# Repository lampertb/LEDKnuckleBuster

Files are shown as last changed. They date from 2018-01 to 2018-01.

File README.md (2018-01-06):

[gif]: https://github.com/lampertb/LEDKnuckleBuster/blob/master/Images/touchExample.gif "LED Knuckle Buster In Action"
[datasheet]: https://github.com/lampertb/LEDKnuckleBuster/blob/master/Images/datasheet.png "Darlington NPN Datasheet"
[dxfExample]: https://github.com/lampertb/LEDKnuckleBuster/blob/master/Images/dxfExample.png "Exporting DXF Design"
[equation1]: https://github.com/lampertb/LEDKnuckleBuster/blob/master/Images/equation1.png "Base current equation"
[equation2]: https://github.com/lampertb/LEDKnuckleBuster/blob/master/Images/equation2.png "Base current equation"
[equation3]: https://github.com/lampertb/LEDKnuckleBuster/blob/master/Images/equation3.png "Base current equation"

[handFist]: https://github.com/lampertb/LEDKnuckleBuster/blob/master/Images/handFist.jpg "LED Knuckle Buster In Action"
[layout]: https://github.com/lampertb/LEDKnuckleBuster/blob/master/Images/layout.png "Board layout with fill"
[productPhoto]: https://github.com/lampertb/LEDKnuckleBuster/blob/master/Images/productPhoto.jpg "LED Knuckle Buster In Action"
[schematic]: https://github.com/lampertb/LEDKnuckleBuster/blob/master/Images/schematic.png "LED Knuckle Buster Schematic"

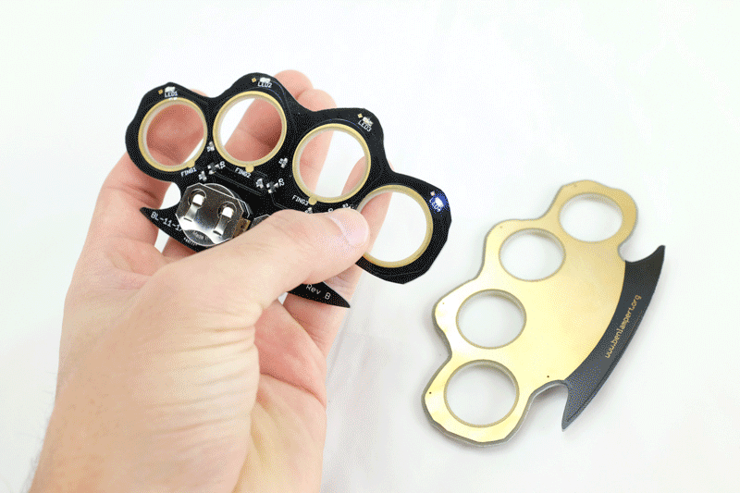
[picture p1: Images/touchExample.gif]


# LED Knuckle Busters, light up your fists!
## By Ben Lampert

Designed and manufactured by Ben Lampert at Chicago's mHub maker space (https://mhubchicago.com/) these LED's brass knuckles are a fun toy to play with. Conductive finger holes turn on high gain transistors that lights up LED's based on the strength of the grip; just put your fingers through the hole and squeeze!

* Features:
  * Brass knuckle finger spacing fits most adults and children.
  * 100% Analog circuitry features low power operation when not in use.
  * Touch sensitive design, just make a fist to turn on the LED's!

* Requires:
  * Blue LED Brass Knuckle board (.brd files available)
  * Parts http://www.digikey.com/short/q8q7pt

* Specs
  * Height: Approx 115mm
  * Width: Approx 50mm
  * Powered by two coin cell batteries

## Project Details:

The LED Knuckle Buster mechanical and board outline was originally inspired by this thingiverse brass knuckle.
https://www.thingiverse.com/thing:1160010

I decided to make an LED version, and after downloading used solidworks to create and exporting a DXF of the outer perimeter of the model. This DXF was then important as layer 20 (board outline) in eagle to create the PCB board outline.

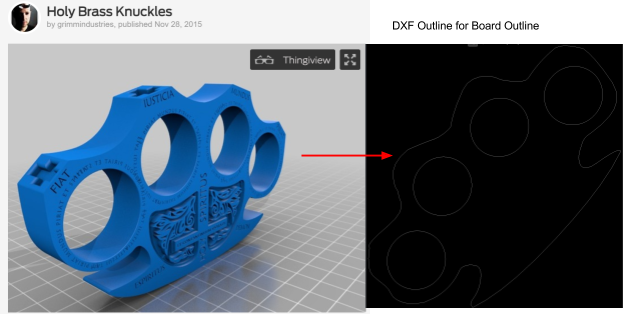
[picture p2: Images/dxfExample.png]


The circuit I think it pretty clever. I originally thought to use a microcontroller and a technique similar to the mAkey mAkey (https://makeymakey.com/). However, it seems like I put MCU’s on everything these days, so I revisited a 100% analog design.

What I came up with I think it simple and clever. The copper on the backside of the board is a VCC plan, as the fingers extend through the holes that make contact with the base of a darlignton pair. Given you skin resistivity is ~100k (https://www.ncbi.nlm.nih.gov/pmc/articles/PMC2763825/) you get a small amount of current running through your fingers.

Just as a ballpark, that current using a Darlington Pair is approximately:







Reviewing the cheapest Darlington Pair NPN available on Digikey
https://www.diodes.com/assets/Datasheets/ds30047.pdf

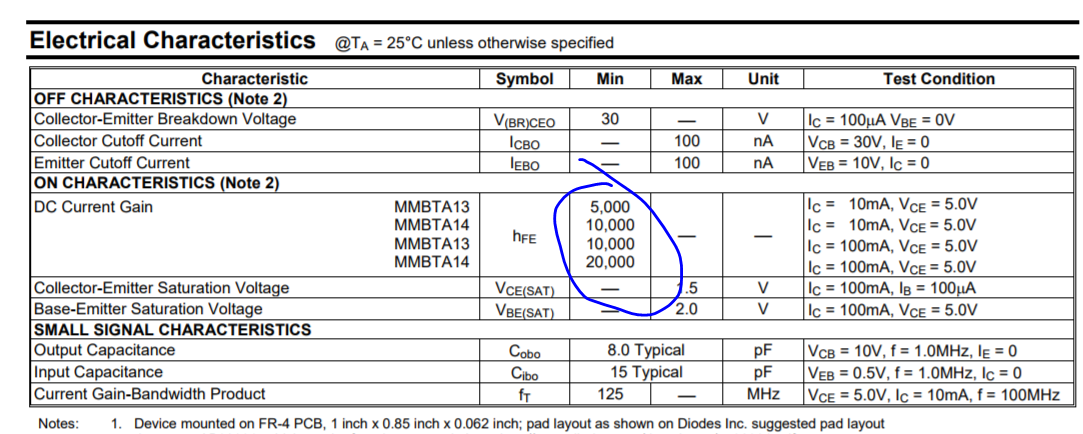
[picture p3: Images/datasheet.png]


This has a gain of 5,000-10,000. So our 46uA base current becomes 23-46mA of current. Not bad for small leakage through your finger!

That current is plenty to turn on a LED, so with that in mind this is the final circuit I designed.

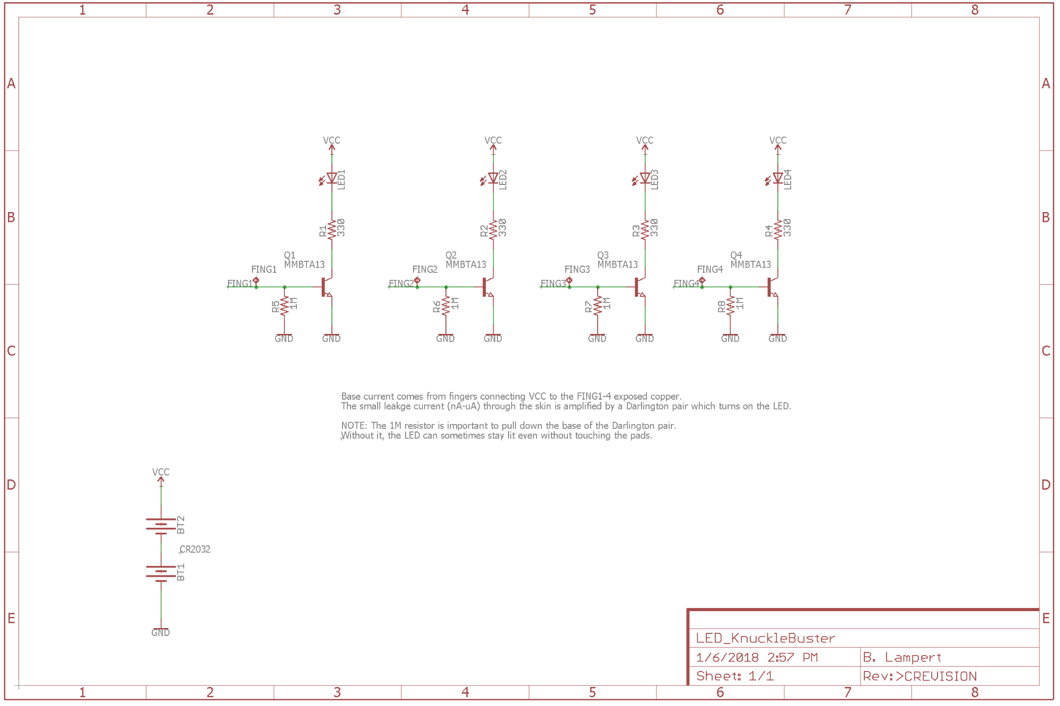
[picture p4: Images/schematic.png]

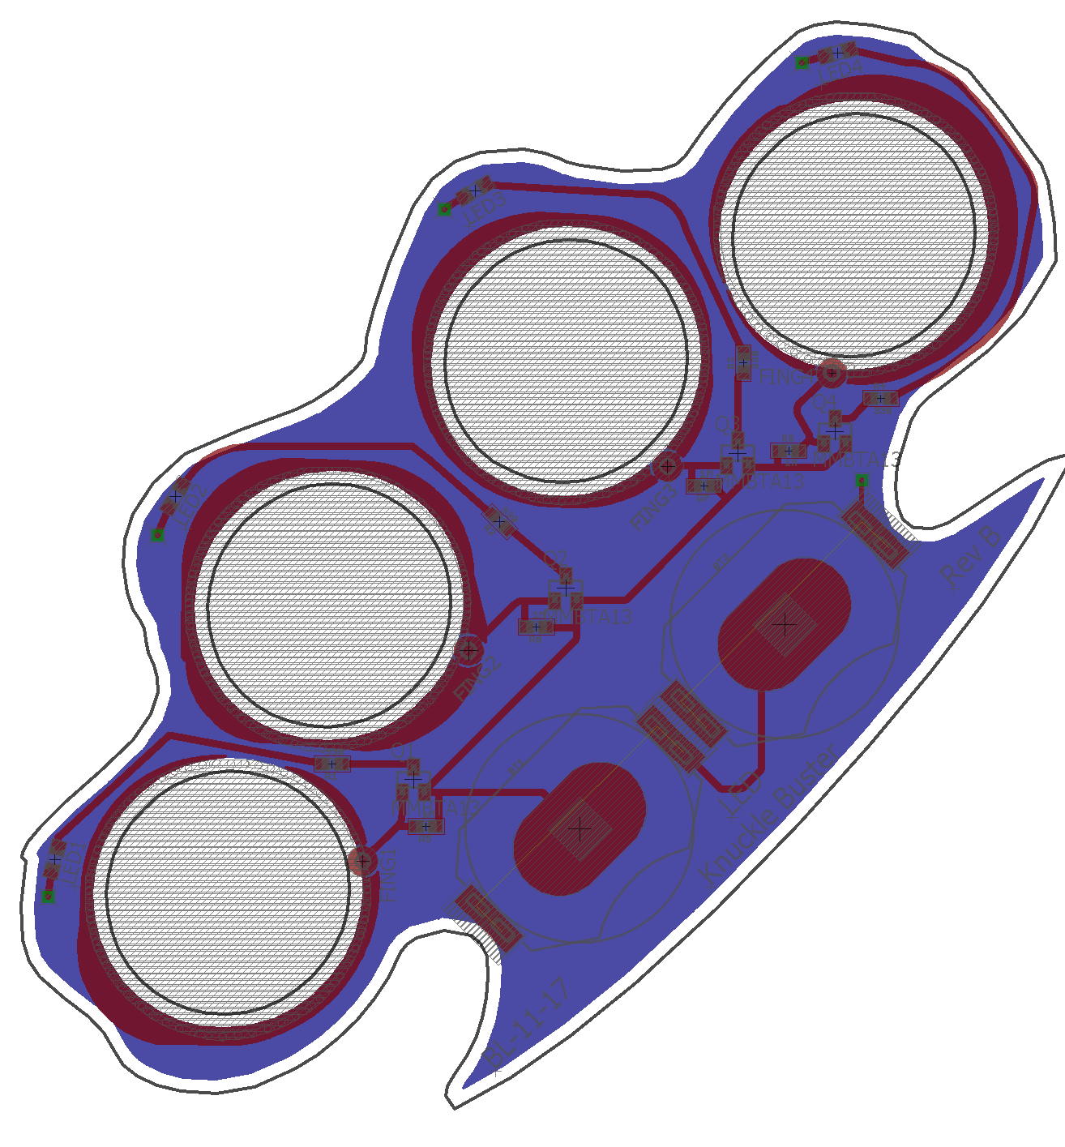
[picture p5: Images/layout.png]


Rev A:
Forgot to connect the via for VCC to connect to the other side of the board, whoop!
Also, forgot a pull down on the base which caused FING4 LED to always be on.

Rev B:
Everything is tested ok! Time to Ship It!

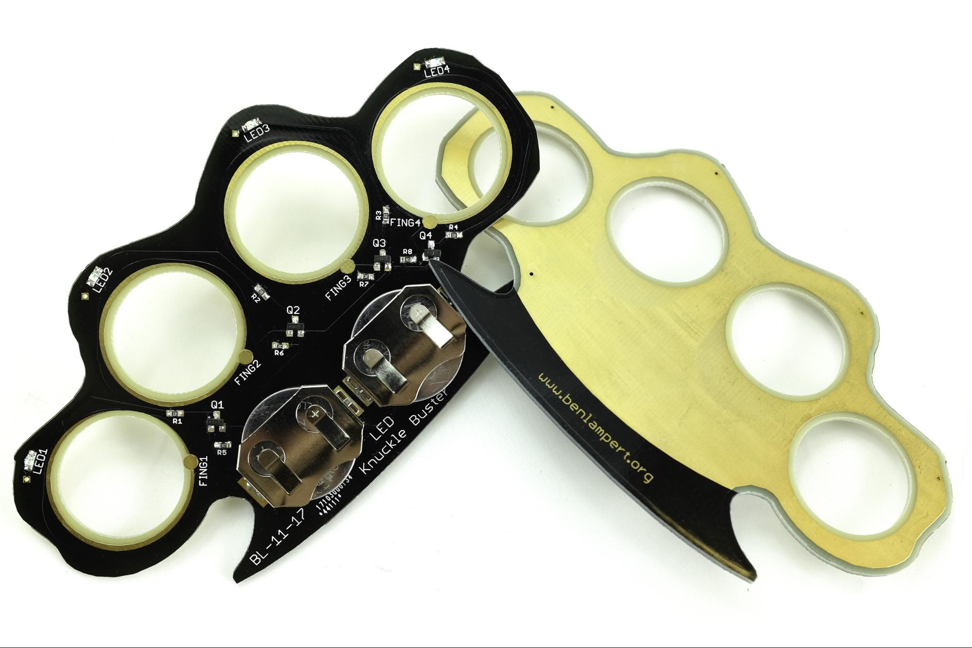
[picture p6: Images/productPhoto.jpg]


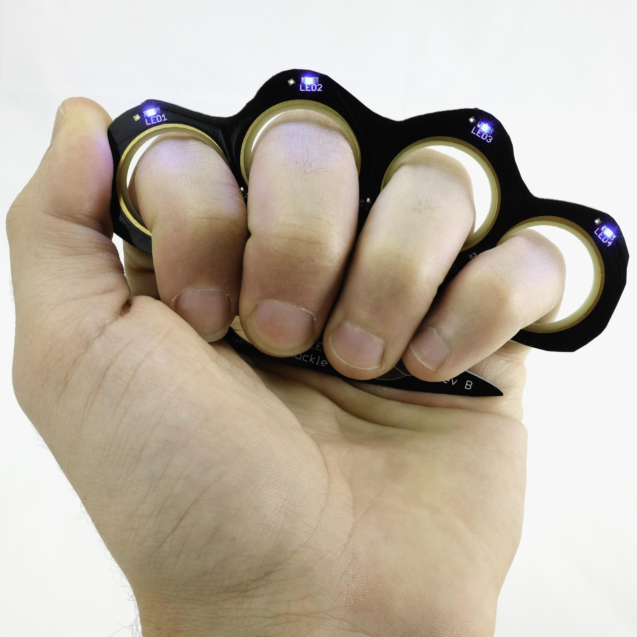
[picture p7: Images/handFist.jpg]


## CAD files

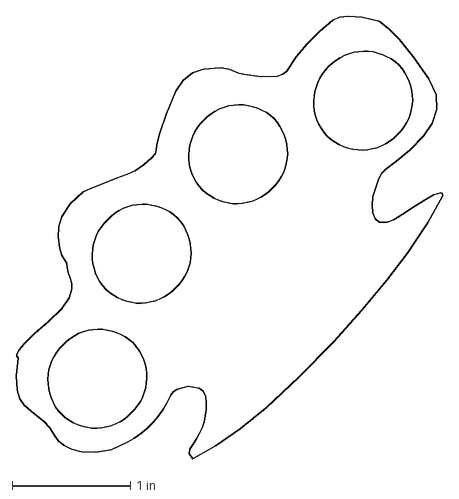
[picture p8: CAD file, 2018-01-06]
Mechanical/Knuckle_Buster_Outline.DXF
3.61 x 3.75 in

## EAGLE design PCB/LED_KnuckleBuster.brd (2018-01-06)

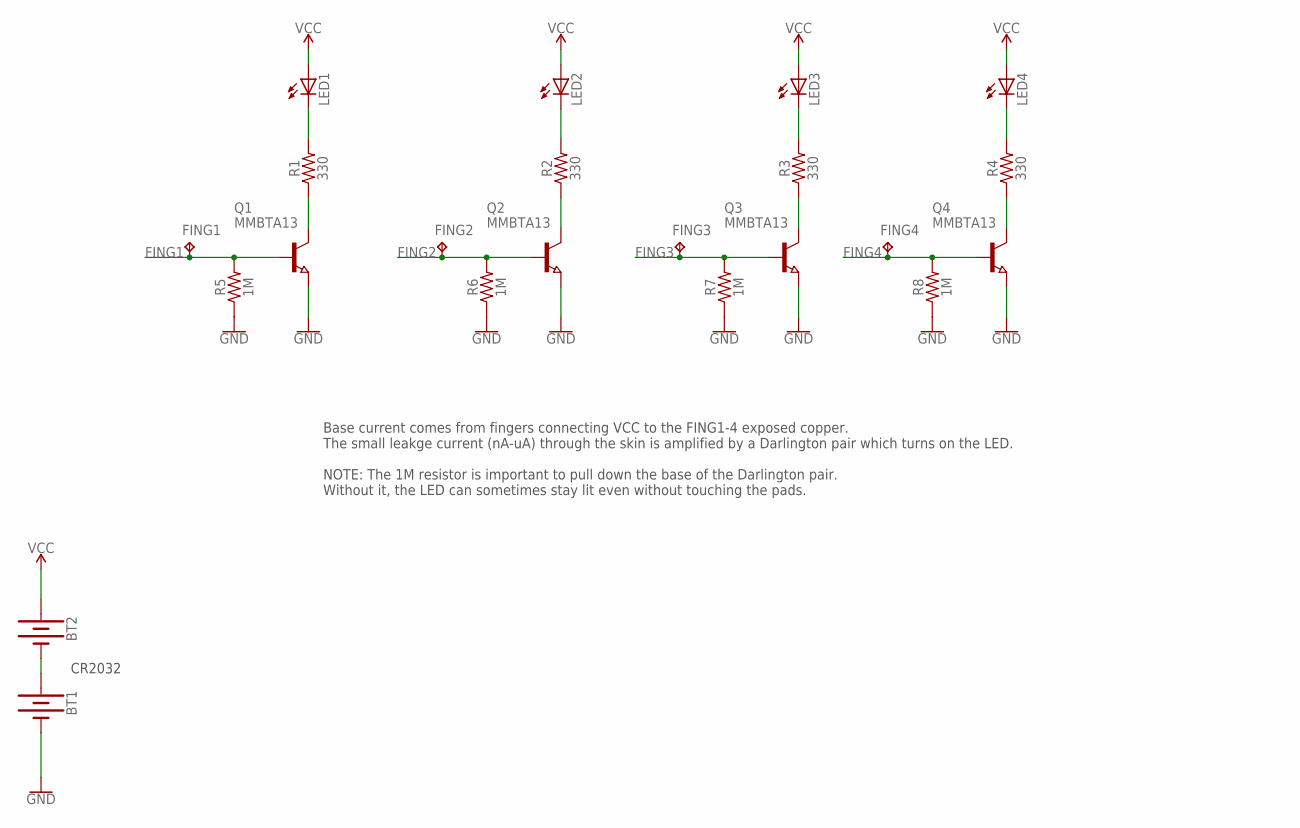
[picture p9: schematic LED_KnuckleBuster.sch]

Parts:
BT1, BT2: BATTERY-20MM_SMD_4LEGS; BATTCON_20MM_4LEGS
FING1, FING2, FING3, FING4: TPB2,54; B2,54
LED1, LED2, LED3, LED4: LEDCHIPLED_0805; CHIPLED_0805
Q1, Q2, Q3, Q4: MMBTA13; SOT23
R1, R2, R3, R4: 330; 0603
R5, R6, R7, R8: 1M; 0603

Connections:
FING1: FING1.TP, Q1.1 (B), R5.2
FING2: FING2.TP, Q2.1 (B), R6.2
FING3: FING3.TP, Q3.1 (B), R7.2
FING4: FING4.TP, Q4.1 (B), R8.2
GND: BT1.NEGATIVE (-), Q1.2 (E), Q2.2 (E), Q3.2 (E), Q4.2 (E), R5.1, R6.1, R7.1, R8.1
unnamed: Q1.3 (C), R1.1
unnamed: LED1.C, R1.2
unnamed: Q2.3 (C), R2.1
unnamed: LED2.C, R2.2
unnamed: Q3.3 (C), R3.1
unnamed: LED3.C, R3.2
unnamed: Q4.3 (C), R4.1
unnamed: LED4.C, R4.2
unnamed: BT1.POSITIVE@1 (+), BT1.POSITIVE@2 (+), BT1.POSITIVE@3 (+), BT1.POSITIVE@4 (+), BT2.NEGATIVE (-)
VCC: BT2.POSITIVE@1 (+), BT2.POSITIVE@2 (+), BT2.POSITIVE@3 (+), BT2.POSITIVE@4 (+), LED1.A, LED2.A, LED3.A, LED4.A

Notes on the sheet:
Base current comes from fingers connecting VCC to the FING1-4 exposed copper. The small leakge current (nA-uA) through the skin is amplified by a Darlington pair which turns on the LED. NOTE: The 1M resistor is important to pull down the base of the Darlington pair. Without it, the LED can sometime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
CR2032

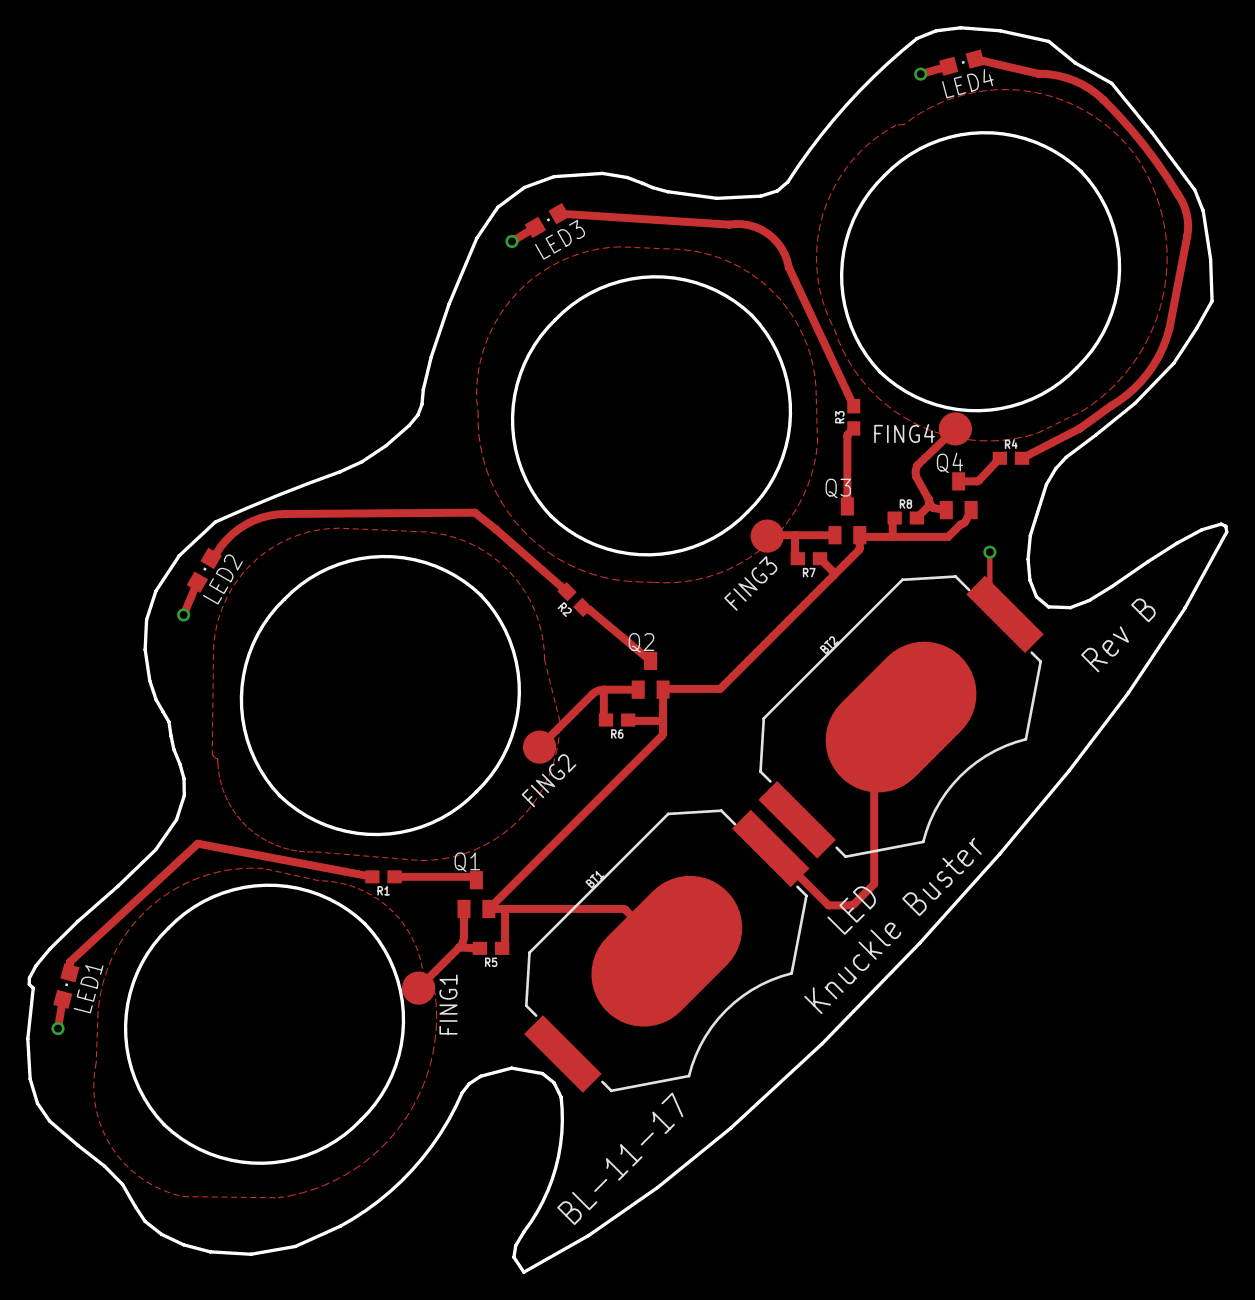
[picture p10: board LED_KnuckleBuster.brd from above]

Board: 2 copper layers, 91.7 x 95.2 mm, 22 parts (0 on the bottom side), 15 nets.

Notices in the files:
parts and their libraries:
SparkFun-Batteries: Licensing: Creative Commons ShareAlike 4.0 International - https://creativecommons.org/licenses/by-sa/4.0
